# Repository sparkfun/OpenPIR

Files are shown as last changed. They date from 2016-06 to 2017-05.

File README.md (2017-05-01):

OpenPIR
==========

[OpenPIR Image*OpenPIR
(SEN-13968)*](https://www.sparkfun.com/products/13968)

OpenPIR is an open source general purpose passive long-wave infrared motion 
detection sensor.

Repository Contents
-------------------
* **/Documentation** - Datasheets for parts used in this design
* **/Hardware** - All Eagle design files
* **/Production** - Panel files used by SFE production for ordering

License Information
-------------------
The hardware is released under [Creative Commons Share-alike
4.0](http://creativecommons.org/licenses/by-sa/4.0/).  
All other code is open source so please feel free to do anything you want with
it; you buy me a beer if you use this and we meet someday ([Beerware
license](http://en.wikipedia.org/wiki/Beerware)).

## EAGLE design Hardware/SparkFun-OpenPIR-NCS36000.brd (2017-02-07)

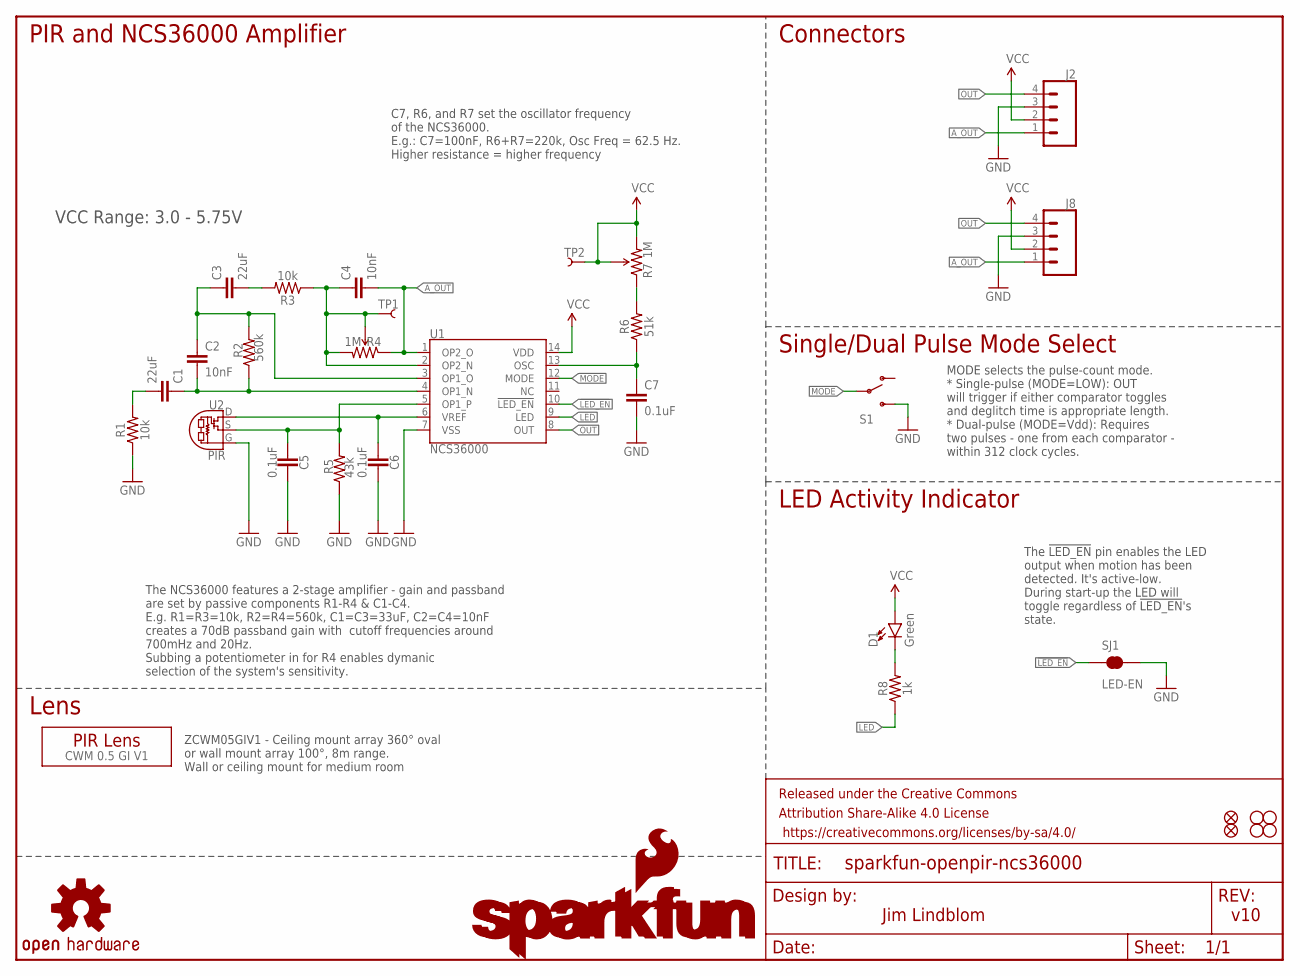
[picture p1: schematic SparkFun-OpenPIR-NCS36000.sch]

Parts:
C1, C3: 22uF; 0805
C2, C4: 10nF; 0603
C5, C6, C7: 0.1uF; 0603
D1: Green; LED-1206-BOTTOM
FD1, FD2: FIDUCIALUFIDUCIAL; MICRO-FIDUCIAL
FRAME1: FRAME-LETTER; CREATIVE_COMMONS
H1, H2, H3, H4: STAND-OFF
J2: CONN_04JST-PTH-VERT-NS; JST-4-PTH-VERT-NS
J8: CONN_04NO_SILK_ALL_ROUND; 1X04_NO_SILK_ALL_ROUND
LOGO1: SFE_LOGO_NAME_FLAME.1_INCH; SFE_LOGO_NAME_FLAME_.1
LOGO3: SFE_LOGO_NAME.1_INCH; SFE_LOGO_NAME_.1
LOGO4: OSHW-LOGOS; OSHW-LOGO-S
R1, R3: 10k; 0603
R2: 560k; 0603
R4, R7: 1M; TRIMPOT-TC33X
R5: 43k; 0603
R6: 51k; 0603
R8: 1k; 0603
S1: SWITCH-SPDT-SMD-A; SWITCH-SPST-SMD-A
SJ1: LED-EN; SJ_2S
TP1, TP2: TEST-POINT3X5; PAD.03X.05
U1: NCS36000; SO14
U2: PIR
U$1: CWM 0.5 GI V1; LENS-CWM-0.5-GI-V1

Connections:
!LED_EN!: SJ1.1, U1.10 (!LED_EN!)
A_OUT: C4.2, J2.1, J8.1, R4.1 (CCW), U1.1 (OP2_O)
GND: C5.2, C6.2, C7.2, J2.3, J8.3, R1.1, R5.1, S1.3 (S), SJ1.2, U1.7 (VSS), U2.G
LED: R8.1, U1.9 (LED)
MODE: S1.2, U1.12 (MODE)
unnamed: C5.1, R5.2, U1.5 (OP1_P), U2.S
unnamed: C6.1, U1.6 (VREF), U2.D
unnamed: C1.2, R1.2
unnamed: C3.2, R3.2
unnamed: C1.1, C2.2, R2.1, U1.4 (OP1_N)
unnamed: C2.1, C3.1, R2.2, U1.3 (OP1_O)
unnamed: C4.1, R3.1, R4.2 (WIPER), R4.3 (CW), TP1.P$1, U1.2 (OP2_N)
unnamed: C7.1, R6.1, U1.13 (OSC)
unnamed: D1.C, R8.2
unnamed: R6.2, R7.1 (CCW)
OUT: J2.4, J8.4, U1.8 (OUT)
VCC: D1.A, J2.2, J8.2, R7.2 (WIPER), R7.3 (CW), TP2.P$1, U1.14 (VDD)

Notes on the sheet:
The !LED_EN! pin enables the LED output when motion has been detected. It's active-low. During start-up the LED will toggle regardless of !LED_EN!'s state.
MODE selects the pulse-count mode. * Single-pulse (MODE=LOW): OUT will trigger if either comparator toggles and deglitch time is appropriate length. * Dual-pulse (MODE=Vdd): Requires two pulses - one from each comparator - within 312 clock cycles.
Jim Lindblom
v10
VCC Range: 3.0 - 5.75V
The NCS36000 features a 2-stage amplifier - gain and passband are set by passive components R1-R4 & C1-C4. E.g. R1=R3=10k, R2=R4=560k, C1=C3=33uF, C2=C4=10nF creates a 70dB passband gain with cutoff frequencies around 700mHz and 20Hz. Subbing a potentiometer in for R4 enables dymanic selection of t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
C7, R6, and R7 set the oscillator frequency of the NCS36000. E.g.: C7=100nF, R6+R7=220k, Osc Freq = 62.5 Hz. Higher resistance = higher frequency
ZCWM05GIV1 - Ceiling mount array 360° oval or wall mount array 100°, 8m range. Wall or ceiling mount for medium room
PIR and NCS36000 Amplifier
Connectors
Single/Dual Pulse Mode Select
LED Activity Indicator
Lens

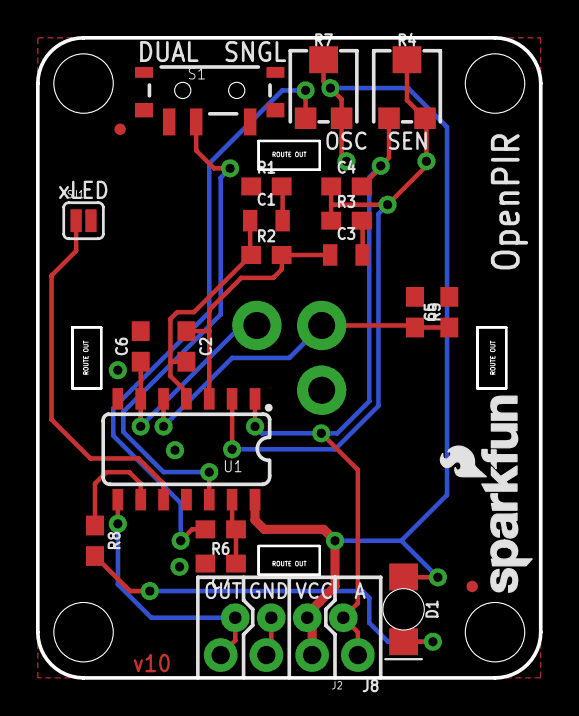
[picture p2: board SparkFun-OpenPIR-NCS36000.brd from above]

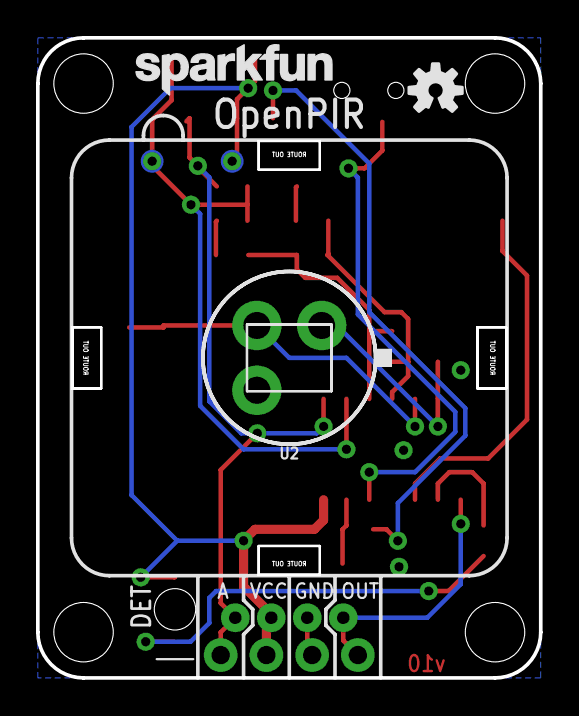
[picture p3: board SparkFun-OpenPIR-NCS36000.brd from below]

Board: 2 copper layers, 27.9 x 35.6 mm, 35 parts (6 on the bottom side), 17 nets.

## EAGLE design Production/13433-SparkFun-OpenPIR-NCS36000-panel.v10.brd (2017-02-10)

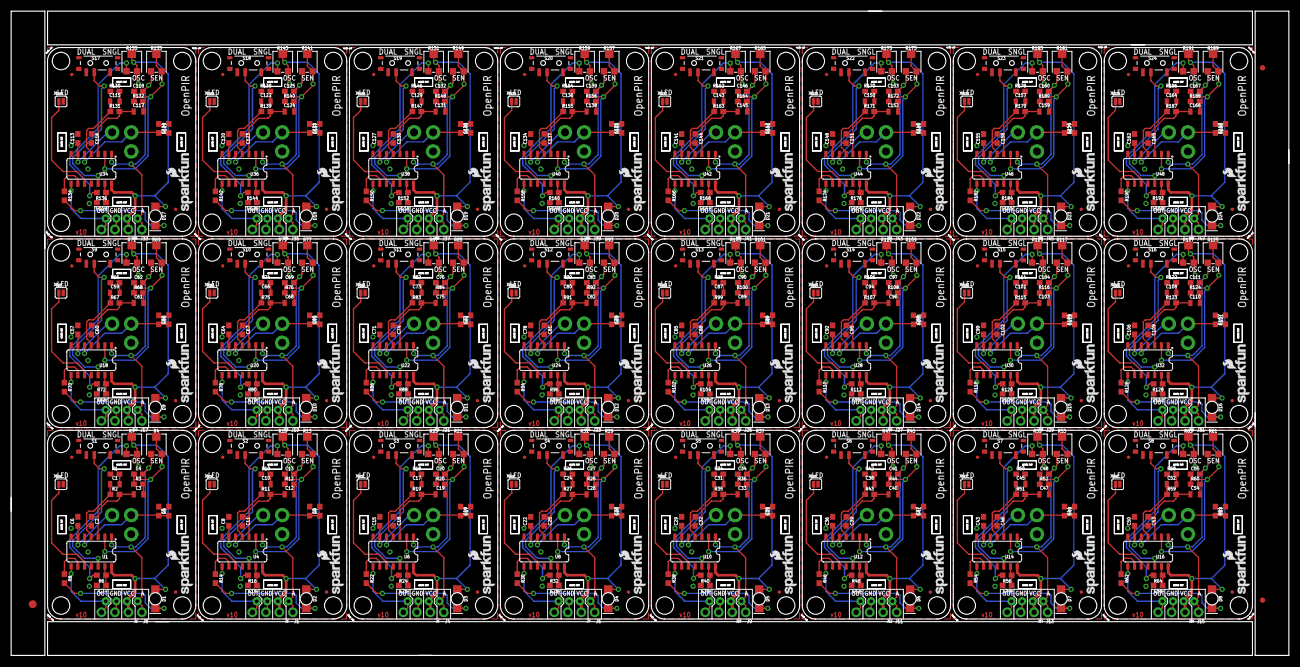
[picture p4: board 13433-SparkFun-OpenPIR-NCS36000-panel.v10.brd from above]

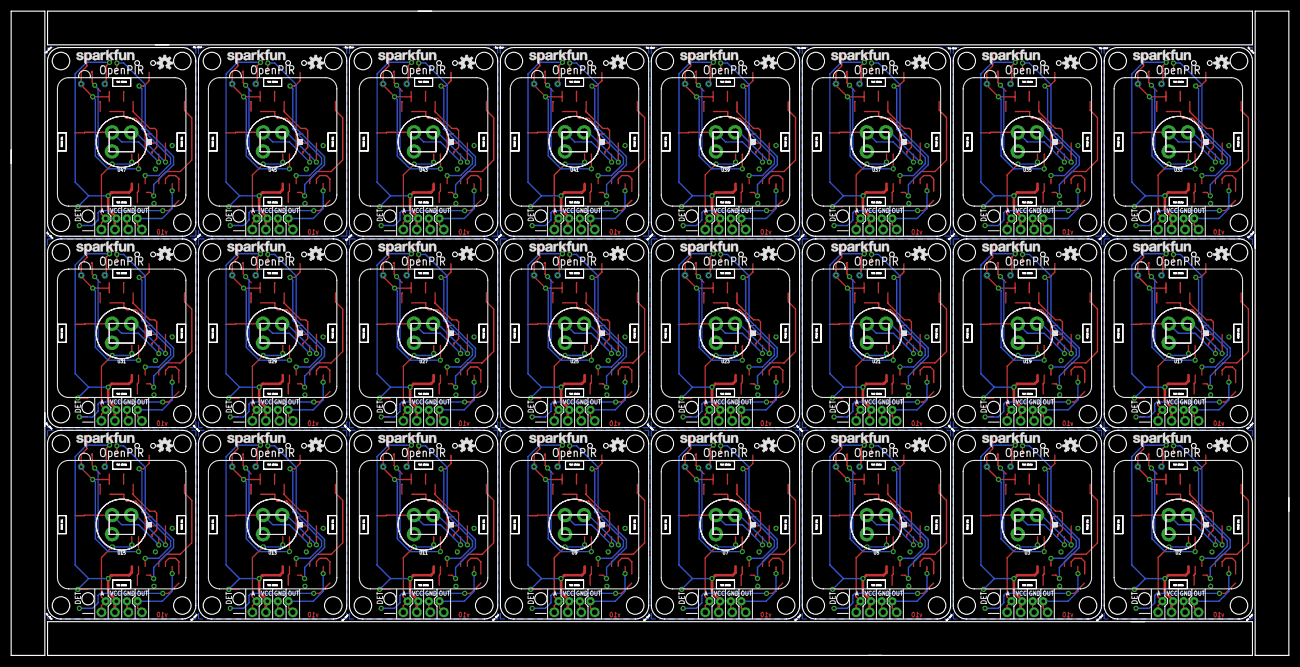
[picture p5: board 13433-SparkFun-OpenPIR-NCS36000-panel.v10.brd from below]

Board: 2 copper layers, 240.8 x 121.4 mm, 819 parts (144 on the bottom side), 408 nets.

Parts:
C1, C3, C10, C12, C17, C19, C24, C26, C31, C33, C38, C40, C45, C47, C52, C54, C59, C61, C66, C68, C73, C75, C80, C82, C87, C89, C94, C96, C101, C103, C108, C110, C115, C117, C122, C124, C129, C131, C136, C138, C143, C145, C150, C152, C157, C159, C164, C166: 22uF; 0805
C2, C4, C11, C13, C18, C20, C25, C27, C32, C34, C39, C41, C46, C48, C53, C55, C60, C62, C67, C69, C74, C76, C81, C83, C88, C90, C95, C97, C102, C104, C109, C111, C116, C118, C123, C125, C130, C132, C137, C139, C144, C146, C151, C153, C158, C160, C165, C167: 10nF; 0603
C5, C6, C7, C8, C9, C14, C15, C16, C21, C22, C23, C28, C29, C30, C35, C36, C37, C42, C43, C44, C49, C50, C51, C56, C57, C58, C63, C64, C65, C70, C71, C72, C77, C78, C79, C84, C85, C86, C91, C92, C93, C98, C99, C100, C105, C106, C107, C112, C113, C114, C119, C120, C121, C126, C127, C128, C133, C134, C135, C140, C141, C142, C147, C148, C149, C154, C155, C156, C161, C162, C163, C168: 0.1uF; 0603
D1, D2, D3, D4, D5, D6, D7, D8, D9, D10, D11, D12, D13, D14, D15, D16, D17, D18, D19, D20, D21, D22, D23, D24: Green; LED-1206-BOTTOM
E$1: FIDUCIAL-1.5X3
E$5, E$6: FIDUCIAL-1X2
FD1, FD2, FD3, FD4, FD5, FD6, FD7, FD8, FD9, FD10, FD11, FD12, FD13, FD14, FD15, FD16, FD17, FD18, FD19, FD20, FD21, FD22, FD23, FD24, FD25, FD26, FD27, FD28, FD29, FD30, FD31, FD32, FD33, FD34, FD35, FD36, FD37, FD38, FD39, FD40, FD41, FD42, FD43, FD44, FD45, FD46, FD47, FD48: FIDUCIALUFIDUCIAL; MICRO-FIDUCIAL
H1, H2, H3, H4, H5, H6, H7, H8, H9, H10, H11, H12, H13, H14, H15, H16, H17, H18, H19, H20, H21, H22, H23, H24, H25, H26, H27, H28, H29, H30, H31, H32, H33, H34, H35, H36, H37, H38, H39, H40, H41, H42, H43, H44, H45, H46, H47, H48, H49, H50, H51, H52, H53, H54, H55, H56, H57, H58, H59, H60, H61, H62, H63, H64, H65, H66, H67, H68, H69, H70, H71, H72, H73, H74, H75, H76, H77, H78, H79, H80, H81, H82, H83, H84, H85, H86, H87, H88, H89, H90, H91, H92, H93, H94, H95, H96: STAND-OFF
J1, J4, J6, J8, J9, J11, J13, J15, J17, J19, J21, J23, J25, J27, J29, J31, J33, J35, J37, J39, J41, J43, J45, J47: 1X04_NO_SILK_ALL_ROUND
J2, J3, J5, J7, J10, J12, J14, J16, J18, J20, J22, J24, J26, J28, J30, J32, J34, J36, J38, J40, J42, J44, J46, J48: JST-4-PTH-VERT-NS
LOGO1, LOGO2, LOGO7, LOGO10, LOGO13, LOGO16, LOGO19, LOGO22, LOGO25, LOGO28, LOGO31, LOGO34, LOGO37, LOGO40, LOGO43, LOGO46, LOGO49, LOGO52, LOGO55, LOGO58, LOGO61, LOGO64, LOGO67, LOGO70: SFE_LOGO_NAME_FLAME.1_INCH; SFE_LOGO_NAME_FLAME_.1
LOGO3, LOGO5, LOGO8, LOGO11, LOGO14, LOGO17, LOGO20, LOGO23, LOGO26, LOGO29, LOGO32, LOGO35, LOGO38, LOGO41, LOGO44, LOGO47, LOGO50, LOGO53, LOGO56, LOGO59, LOGO62, LOGO65, LOGO68, LOGO71: SFE_LOGO_NAME.1_INCH; SFE_LOGO_NAME_.1
LOGO4, LOGO6, LOGO9, LOGO12, LOGO15, LOGO18, LOGO21, LOGO24, LOGO27, LOGO30, LOGO33, LOGO36, LOGO39, LOGO42, LOGO45, LOGO48, LOGO51, LOGO54, LOGO57, LOGO60, LOGO63, LOGO66, LOGO69, LOGO72: OSHW-LOGOS; OSHW-LOGO-S
R1, R3, R10, R12, R18, R20, R26, R28, R34, R36, R42, R44, R50, R52, R58, R60, R66, R68, R74, R76, R82, R84, R90, R92, R98, R100, R106, R108, R114, R116, R122, R124, R130, R132, R138, R140, R146, R148, R154, R156, R162, R164, R170, R172, R178, R180, R186, R188: 10k; 0603
R2, R11, R19, R27, R35, R43, R51, R59, R67, R75, R83, R91, R99, R107, R115, R123, R131, R139, R147, R155, R163, R171, R179, R187: 560k; 0603
R4, R7, R13, R15, R21, R23, R29, R31, R37, R39, R45, R47, R53, R55, R61, R63, R69, R71, R77, R79, R85, R87, R93, R95, R101, R103, R109, R111, R117, R119, R125, R127, R133, R135, R141, R143, R149, R151, R157, R159, R165, R167, R173, R175, R181, R183, R189, R191: 1M; TRIMPOT-TC33X
R5, R9, R17, R25, R33, R41, R49, R57, R65, R73, R81, R89, R97, R105, R113, R121, R129, R137, R145, R153, R161, R169, R177, R185: 43k; 0603
R6, R16, R24, R32, R40, R48, R56, R64, R72, R80, R88, R96, R104, R112, R120, R128, R136, R144, R152, R160, R168, R176, R184, R192: 51k; 0603
R8, R14, R22, R30, R38, R46, R54, R62, R70, R78, R86, R94, R102, R110, R118, R126, R134, R142, R150, R158, R166, R174, R182, R190: 1k; 0603
S1, S2, S3, S4, S5, S6, S7, S8, S9, S10, S11, S12, S13, S14, S15, S16, S17, S18, S19, S20, S21, S22, S23, S24: SWITCH-SPST-SMD-A
SJ1, SJ2, SJ3, SJ4, SJ5, SJ6, SJ7, SJ8, SJ9, SJ10, SJ11, SJ12, SJ13, SJ14, SJ15, SJ16, SJ17, SJ18, SJ19, SJ20, SJ21, SJ22, SJ23, SJ24: LED-EN; SJ_2S
TP1, TP2, TP3, TP4, TP5, TP6, TP7, TP8, TP9, TP10, TP11, TP12, TP13, TP14, TP15, TP16, TP17, TP18, TP19, TP20, TP21, TP22, TP23, TP24, TP25, TP26, TP27, TP28, TP29, TP30, TP31, TP32, TP33, TP34, TP35, TP36, TP37, TP38, TP39, TP40, TP41, TP42, TP43, TP44, TP45, TP46, TP47, TP48: PAD.03X.05
U1, U4, U6, U8, U10, U12, U14, U16, U18, U20, U22, U24, U26, U28, U30, U32, U34, U36, U38, U40, U42, U44, U46, U48: NCS36000; SO14
U2, U3, U5, U7, U9, U11, U13, U15, U17, U19, U21, U23, U25, U27, U29, U31, U33, U35, U37, U39, U41, U43, U45, U47: PIR
U$1, U$2, U$3, U$4, U$5, U$6, U$7, U$8, U$9, U$10, U$11, U$12, U$13, U$14, U$15, U$16, U$17, U$18, U$19, U$20, U$21, U$22, U$23, U$24: CWM 0.5 GI V1; LENS-CWM-0.5-GI-V1

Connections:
!LED_EN!: SJ1.1, U1.10
!LED_EN!1: SJ2.1, U4.10
!LED_EN!2: SJ3.1, U6.10
!LED_EN!3: SJ4.1, U8.10
!LED_EN!4: SJ5.1, U10.10
!LED_EN!5: SJ6.1, U12.10
!LED_EN!6: SJ7.1, U14.10
!LED_EN!7: SJ8.1, U16.10
!LED_EN!8: SJ9.1, U18.10
!LED_EN!9: SJ10.1, U20.10
!LED_EN!10: SJ11.1, U22.10
!LED_EN!11: SJ12.1, U24.10
!LED_EN!12: SJ13.1, U26.10
!LED_EN!13: SJ14.1, U28.10
!LED_EN!14: SJ15.1, U30.10
!LED_EN!15: SJ16.1, U32.10
!LED_EN!16: SJ17.1, U34.10
!LED_EN!17: SJ18.1, U36.10
!LED_EN!18: SJ19.1, U38.10
!LED_EN!19: SJ20.1, U40.10
!LED_EN!20: SJ21.1, U42.10
!LED_EN!21: SJ22.1, U44.10
!LED_EN!22: SJ23.1, U46.10
!LED_EN!23: SJ24.1, U48.10
A_OUT: C4.2, J2.1, J8.1, R4.1, U1.1
A_OUT1: C13.2, J1.1, J3.1, R13.1, U4.1
A_OUT2: C20.2, J4.1, J5.1, R21.1, U6.1
A_OUT3: C27.2, J6.1, J7.1, R29.1, U8.1
A_OUT4: C34.2, J9.1, J10.1, R37.1, U10.1
A_OUT5: C41.2, J11.1, J12.1, R45.1, U12.1
A_OUT6: C48.2, J13.1, J14.1, R53.1, U14.1
A_OUT7: C55.2, J15.1, J16.1, R61.1, U16.1
A_OUT8: C62.2, J17.1, J18.1, R69.1, U18.1
A_OUT9: C69.2, J19.1, J20.1, R77.1, U20.1
A_OUT10: C76.2, J21.1, J22.1, R85.1, U22.1
A_OUT11: C83.2, J23.1, J24.1, R93.1, U24.1
A_OUT12: C90.2, J25.1, J26.1, R101.1, U26.1
A_OUT13: C97.2, J27.1, J28.1, R109.1, U28.1
A_OUT14: C104.2, J29.1, J30.1, R117.1, U30.1
A_OUT15: C111.2, J31.1, J32.1, R125.1, U32.1
A_OUT16: C118.2, J33.1, J34.1, R133.1, U34.1
A_OUT17: C125.2, J35.1, J36.1, R141.1, U36.1
A_OUT18: C132.2, J37.1, J38.1, R149.1, U38.1
A_OUT19: C139.2, J39.1, J40.1, R157.1, U40.1
A_OUT20: C146.2, J41.1, J42.1, R165.1, U42.1
A_OUT21: C153.2, J43.1, J44.1, R173.1, U44.1
A_OUT22: C160.2, J45.1, J46.1, R181.1, U46.1
A_OUT23: C167.2, J47.1, J48.1, R189.1, U48.1
GND: C5.2, C6.2, C7.2, J2.3, J8.3, R1.1, R5.1, S1.3, SJ1.2, U1.7, U2.G
GND1: C8.2, C9.2, C14.2, J1.3, J3.3, R9.1, R10.1, S2.3, SJ2.2, U3.G, U4.7
GND2: C15.2, C16.2, C21.2, J4.3, J5.3, R17.1, R18.1, S3.3, SJ3.2, U5.G, U6.7
GND3: C22.2, C23.2, C28.2, J6.3, J7.3, R25.1, R26.1, S4.3, SJ4.2, U7.G, U8.7
GND4: C29.2, C30.2, C35.2, J9.3, J10.3, R33.1, R34.1, S5.3, SJ5.2, U9.G, U10.7
GND5: C36.2, C37.2, C42.2, J11.3, J12.3, R41.1, R42.1, S6.3, SJ6.2, U11.G, U12.7
GND6: C43.2, C44.2, C49.2, J13.3, J14.3, R49.1, R50.1, S7.3, SJ7.2, U13.G, U14.7
GND7: C50.2, C51.2, C56.2, J15.3, J16.3, R57.1, R58.1, S8.3, SJ8.2, U15.G, U16.7
GND8: C57.2, C58.2, C63.2, J17.3, J18.3, R65.1, R66.1, S9.3, SJ9.2, U17.G, U18.7
GND9: C64.2, C65.2, C70.2, J19.3, J20.3, R73.1, R74.1, S10.3, SJ10.2, U19.G, U20.7
GND10: C71.2, C72.2, C77.2, J21.3, J22.3, R81.1, R82.1, S11.3, SJ11.2, U21.G, U22.7
GND11: C78.2, C79.2, C84.2, J23.3, J24.3, R89.1, R90.1, S12.3, SJ12.2, U23.G, U24.7
GND12: C85.2, C86.2, C91.2, J25.3, J26.3, R97.1, R98.1, S13.3, SJ13.2, U25.G, U26.7
GND13: C92.2, C93.2, C98.2, J27.3, J28.3, R105.1, R106.1, S14.3, SJ14.2, U27.G, U28.7
GND14: C99.2, C100.2, C105.2, J29.3, J30.3, R113.1, R114.1, S15.3, SJ15.2, U29.G, U30.7
GND15: C106.2, C107.2, C112.2, J31.3, J32.3, R121.1, R122.1, S16.3, SJ16.2, U31.G, U32.7
GND16: C113.2, C114.2, C119.2, J33.3, J34.3, R129.1, R130.1, S17.3, SJ17.2, U33.G, U34.7
GND17: C120.2, C121.2, C126.2, J35.3, J36.3, R137.1, R138.1, S18.3, SJ18.2, U35.G, U36.7
GND18: C127.2, C128.2, C133.2, J37.3, J38.3, R145.1, R146.1, S19.3, SJ19.2, U37.G, U38.7
GND19: C134.2, C135.2, C140.2, J39.3, J40.3, R153.1, R154.1, S20.3, SJ20.2, U39.G, U40.7
GND20: C141.2, C142.2, C147.2, J41.3, J42.3, R161.1, R162.1, S21.3, SJ21.2, U41.G, U42.7
GND21: C148.2, C149.2, C154.2, J43.3, J44.3, R169.1, R170.1, S22.3, SJ22.2, U43.G, U44.7
GND22: C155.2, C156.2, C161.2, J45.3, J46.3, R177.1, R178.1, S23.3, SJ23.2, U45.G, U46.7
GND23: C162.2, C163.2, C168.2, J47.3, J48.3, R185.1, R186.1, S24.3, SJ24.2, U47.G, U48.7
LED: R8.1, U1.9
LED1: R14.1, U4.9
LED2: R22.1, U6.9
LED3: R30.1, U8.9
LED4: R38.1, U10.9
LED5: R46.1, U12.9
LED6: R54.1, U14.9
LED7: R62.1, U16.9
LED8: R70.1, U18.9
LED9: R78.1, U20.9
LED10: R86.1, U22.9
LED11: R94.1, U24.9
LED12: R102.1, U26.9
LED13: R110.1, U28.9
LED14: R118.1, U30.9
LED15: R126.1, U32.9
LED16: R134.1, U34.9
LED17: R142.1, U36.9
LED18: R150.1, U38.9
LED19: R158.1, U40.9
LED20: R166.1, U42.9
LED21: R174.1, U44.9
LED22: R182.1, U46.9
LED23: R190.1, U48.9
MODE: S1.2, U1.12
MODE1: S2.2, U4.12
MODE2: S3.2, U6.12
MODE3: S4.2, U8.12
MODE4: S5.2, U10.12
MODE5: S6.2, U12.12
MODE6: S7.2, U14.12
MODE7: S8.2, U16.12
MODE8: S9.2, U18.12
MODE9: S10.2, U20.12
MODE10: S11.2, U22.12
MODE11: S12.2, U24.12
MODE12: S13.2, U26.12
MODE13: S14.2, U28.12
MODE14: S15.2, U30.12
MODE15: S16.2, U32.12
MODE16: S17.2, U34.12
MODE17: S18.2, U36.12
MODE18: S19.2, U38.12
MODE19: S20.2, U40.12
MODE20: S21.2, U42.12
MODE21: S22.2, U44.12
MODE22: S23.2, U46.12
MODE23: S24.2, U48.12
unnamed: C5.1, R5.2, U1.5, U2.S
unnamed: C6.1, U1.6, U2.D
unnamed: C1.2, R1.2
unnamed: C3.2, R3.2
unnamed: C1.1, C2.2, R2.1, U1.4
unnamed: C2.1, C3.1, R2.2, U1.3
unnamed: C4.1, R3.1, R4.2, R4.3, TP1.P$1, U1.2
unnamed: C7.1, R6.1, U1.13
unnamed: D1.C, R8.2
unnamed: C8.1, U3.D, U4.6
unnamed: R6.2, R7.1
unnamed: C9.1, R9.2, U3.S, U4.5
unnamed: C10.2, R10.2
unnamed: C12.2, R12.2
unnamed: C10.1, C11.2, R11.1, U4.4
unnamed: C11.1, C12.1, R11.2, U4.3
unnamed: C13.1, R12.1, R13.2, R13.3, TP3.P$1, U4.2
unnamed: C14.1, R16.1, U4.13
unnamed: D2.C, R14.2
unnamed: R15.1, R16.2
unnamed: C15.1, U5.D, U6.6
unnamed: C16.1, R17.2, U5.S, U6.5
unnamed: C17.2, R18.2
unnamed: C19.2, R20.2
unnamed: C17.1, C18.2, R19.1, U6.4
unnamed: C18.1, C19.1, R19.2, U6.3
unnamed: C20.1, R20.1, R21.2, R21.3, TP5.P$1, U6.2
unnamed: C21.1, R24.1, U6.13
unnamed: D3.C, R22.2
unnamed: R23.1, R24.2
unnamed: C22.1, U7.D, U8.6
unnamed: C23.1, R25.2, U7.S, U8.5
unnamed: C24.2, R26.2
unnamed: C26.2, R28.2
unnamed: C24.1, C25.2, R27.1, U8.4
unnamed: C25.1, C26.1, R27.2, U8.3
unnamed: C27.1, R28.1, R29.2, R29.3, TP7.P$1, U8.2
unnamed: C28.1, R32.1, U8.13
unnamed: D4.C, R30.2
unnamed: R31.1, R32.2
unnamed: C29.1, U9.D, U10.6
unnamed: C30.1, R33.2, U9.S, U10.5
unnamed: C31.2, R34.2
unnamed: C33.2, R36.2
unnamed: C31.1, C32.2, R35.1, U10.4
unnamed: C32.1, C33.1, R35.2, U10.3
unnamed: C34.1, R36.1, R37.2, R37.3, TP9.P$1, U10.2
unnamed: C35.1, R40.1, U10.13
unnamed: D5.C, R38.2
unnamed: R39.1, R40.2
unnamed: C36.1, U11.D, U12.6
unnamed: C37.1, R41.2, U11.S, U12.5
unnamed: C38.2, R42.2
unnamed: C40.2, R44.2
unnamed: C38.1, C39.2, R43.1, U12.4
unnamed: C39.1, C40.1, R43.2, U12.3
unnamed: C41.1, R44.1, R45.2, R45.3, TP11.P$1, U12.2
unnamed: C42.1, R48.1, U12.13
unnamed: D6.C, R46.2
unnamed: R47.1, R48.2
unnamed: C43.1, U13.D, U14.6
unnamed: C44.1, R49.2, U13.S, U14.5
unnamed: C45.2, R50.2
unnamed: C47.2, R52.2
unnamed: C45.1, C46.2, R51.1, U14.4
unnamed: C46.1, C47.1, R51.2, U14.3
unnamed: C48.1, R52.1, R53.2, R53.3, TP13.P$1, U14.2
unnamed: C49.1, R56.1, U14.13
unnamed: D7.C, R54.2
unnamed: R55.1, R56.2
unnamed: C50.1, U15.D, U16.6
unnamed: C51.1, R57.2, U15.S, U16.5
unnamed: C52.2, R58.2
unnamed: C54.2, R60.2
unnamed: C52.1, C53.2, R59.1, U16.4
unnamed: C53.1, C54.1, R59.2, U16.3
unnamed: C55.1, R60.1, R61.2, R61.3, TP15.P$1, U16.2
unnamed: C56.1, R64.1, U16.13
unnamed: D8.C, R62.2
unnamed: R63.1, R64.2
unnamed: C57.1, U17.D, U18.6
unnamed: C58.1, R65.2, U17.S, U18.5
unnamed: C59.2, R66.2
unnamed: C61.2, R68.2
unnamed: C59.1, C60.2, R67.1, U18.4
unnamed: C60.1, C61.1, R67.2, U18.3
unnamed: C62.1, R68.1, R69.2, R69.3, TP17.P$1, U18.2
unnamed: C63.1, R72.1, U18.13
unnamed: D9.C, R70.2
unnamed: R71.1, R72.2
unnamed: C64.1, U19.D, U20.6
unnamed: C65.1, R73.2, U19.S, U20.5
unnamed: C66.2, R74.2
unnamed: C68.2, R76.2
unnamed: C66.1, C67.2, R75.1, U20.4
unnamed: C67.1, C68.1, R75.2, U20.3
unnamed: C69.1, R76.1, R77.2, R77.3, TP19.P$1, U20.2
unnamed: C70.1, R80.1, U20.13
unnamed: D10.C, R78.2
unnamed: R79.1, R80.2
unnamed: C71.1, U21.D, U22.6
unnamed: C72.1, R81.2, U21.S, U22.5
unnamed: C73.2, R82.2
unnamed: C75.2, R84.2
unnamed: C73.1, C74.2, R83.1, U22.4
unnamed: C74.1, C75.1, R83.2, U22.3
unnamed: C76.1, R84.1, R85.2, R85.3, TP21.P$1, U22.2
unnamed: C77.1, R88.1, U22.13
unnamed: D11.C, R86.2
unnamed: R87.1, R88.2
unnamed: C78.1, U23.D, U24.6
unnamed: C79.1, R89.2, U23.S, U24.5
unnamed: C80.2, R90.2
unnamed: C82.2, R92.2
unnamed: C80.1, C81.2, R91.1, U24.4
unnamed: C81.1, C82.1, R91.2, U24.3
unnamed: C83.1, R92.1, R93.2, R93.3, TP23.P$1, U24.2
unnamed: C84.1, R96.1, U24.13
unnamed: D12.C, R94.2
unnamed: R95.1, R96.2
unnamed: C85.1, U25.D, U26.6
unnamed: C86.1, R97.2, U25.S, U26.5
unnamed: C87.2, R98.2
unnamed: C89.2, R100.2
unnamed: C87.1, C88.2, R99.1, U26.4
unnamed: C88.1, C89.1, R99.2, U26.3
unnamed: C90.1, R100.1, R101.2, R101.3, TP25.P$1, U26.2
unnamed: C91.1, R104.1, U26.13
unnamed: D13.C, R102.2
unnamed: R103.1, R104.2
unnamed: C92.1, U27.D, U28.6
unnamed: C93.1, R105.2, U27.S, U28.5
unnamed: C94.2, R106.2
unnamed: C96.2, R108.2
unnamed: C94.1, C95.2, R107.1, U28.4
unnamed: C95.1, C96.1, R107.2, U28.3
unnamed: C97.1, R108.1, R109.2, R109.3, TP27.P$1, U28.2
unnamed: C98.1, R112.1, U28.13
unnamed: D14.C, R110.2
unnamed: R111.1, R112.2
unnamed: C99.1, U29.D, U30.6
unnamed: C100.1, R113.2, U29.S, U30.5
unnamed: C101.2, R114.2
unnamed: C103.2, R116.2
unnamed: C101.1, C102.2, R115.1, U30.4
unnamed: C102.1, C103.1, R115.2, U30.3
unnamed: C104.1, R116.1, R117.2, R117.3, TP29.P$1, U30.2
unnamed: C105.1, R120.1, U30.13
unnamed: D15.C, R118.2
unnamed: R119.1, R120.2
unnamed: C106.1, U31.D, U32.6
unnamed: C107.1, R121.2, U31.S, U32.5
unnamed: C108.2, R122.2
unnamed: C110.2, R124.2
unnamed: C108.1, C109.2, R123.1, U32.4
unnamed: C109.1, C110.1, R123.2, U32.3
unnamed: C111.1, R124.1, R125.2, R125.3, TP31.P$1, U32.2
unnamed: C112.1, R128.1, U32.13
unnamed: D16.C, R126.2
unnamed: R127.1, R128.2
unnamed: C113.1, U33.D, U34.6
unnamed: C114.1, R129.2, U33.S, U34.5
unnamed: C115.2, R130.2
unnamed: C117.2, R132.2
unnamed: C115.1, C116.2, R131.1, U34.4
unnamed: C116.1, C117.1, R131.2, U34.3
unnamed: C118.1, R132.1, R133.2, R133.3, TP33.P$1, U34.2
unnamed: C119.1, R136.1, U34.13
unnamed: D17.C, R134.2
unnamed: R135.1, R136.2
unnamed: C120.1, U35.D, U36.6
unnamed: C121.1, R137.2, U35.S, U36.5
unnamed: C122.2, R138.2
unnamed: C124.2, R140.2
unnamed: C122.1, C123.2, R139.1, U36.4
unnamed: C123.1, C124.1, R139.2, U36.3
unnamed: C125.1, R140.1, R141.2, R141.3, TP35.P$1, U36.2
unnamed: C126.1, R144.1, U36.13
unnamed: D18.C, R142.2
unnamed: R143.1, R144.2
unnamed: C127.1, U37.D, U38.6
unnamed: C128.1, R145.2, U37.S, U38.5
unnamed: C129.2, R146.2
unnamed: C131.2, R148.2
unnamed: C129.1, C130.2, R147.1, U38.4
unnamed: C130.1, C131.1, R147.2, U38.3
unnamed: C132.1, R148.1, R149.2, R149.3, TP37.P$1, U38.2
unnamed: C133.1, R152.1, U38.13
unnamed: D19.C, R150.2
unnamed: R151.1, R152.2
unnamed: C134.1, U39.D, U40.6
unnamed: C135.1, R153.2, U39.S, U40.5
unnamed: C136.2, R154.2
unnamed: C138.2, R156.2
unnamed: C136.1, C137.2, R155.1, U40.4
unnamed: C137.1, C138.1, R155.2, U40.3
unnamed: C139.1, R156.1, R157.2, R157.3, TP39.P$1, U40.2
unnamed: C140.1, R160.1, U40.13
unnamed: D20.C, R158.2
unnamed: R159.1, R160.2
unnamed: C141.1, U41.D, U42.6
unnamed: C142.1, R161.2, U41.S, U42.5
unnamed: C143.2, R162.2
unnamed: C145.2, R164.2
unnamed: C143.1, C144.2, R163.1, U42.4
unnamed: C144.1, C145.1, R163.2, U42.3
unnamed: C146.1, R164.1, R165.2, R165.3, TP41.P$1, U42.2
unnamed: C147.1, R168.1, U42.13
unnamed: D21.C, R166.2
unnamed: R167.1, R168.2
unnamed: C148.1, U43.D, U44.6
unnamed: C149.1, R169.2, U43.S, U44.5
unnamed: C150.2, R170.2
unnamed: C152.2, R172.2
unnamed: C150.1, C151.2, R171.1, U44.4
unnamed: C151.1, C152.1, R171.2, U44.3
unnamed: C153.1, R172.1, R173.2, R173.3, TP43.P$1, U44.2
unnamed: C154.1, R176.1, U44.13
unnamed: D22.C, R174.2
unnamed: R175.1, R176.2
unnamed: C155.1, U45.D, U46.6
unnamed: C156.1, R177.2, U45.S, U46.5
unnamed: C157.2, R178.2
unnamed: C159.2, R180.2
unnamed: C157.1, C158.2, R179.1, U46.4
unnamed: C158.1, C159.1, R179.2, U46.3
unnamed: C160.1, R180.1, R181.2, R181.3, TP45.P$1, U46.2
unnamed: C161.1, R184.1, U46.13
unnamed: D23.C, R182.2
unnamed: R183.1, R184.2
unnamed: C162.1, U47.D, U48.6
unnamed: C163.1, R185.2, U47.S, U48.5
unnamed: C164.2, R186.2
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

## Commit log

2016-06-20 Initial commit of hardware.
    [SparkFun-OpenPIR-NCS36000.brd, SparkFun-OpenPIR-NCS36000.sch]
2016-06-21 Swapping 33uF cap packages to 1206.
    [SparkFun-OpenPIR-NCS36000.brd, SparkFun-OpenPIR-NCS36000.sch]
2016-06-21 Updating sch and brd after running checklist.
    [SparkFun-OpenPIR-NCS36000.brd, SparkFun-OpenPIR-NCS36000.sch]
2016-06-24 Moving route out text to design.
    [SparkFun-OpenPIR-NCS36000.brd, SparkFun-OpenPIR-NCS36000.sch]
2016-06-24 created PROTO panel v01
    [SparkFun-OpenPIR-NCS36000_PROTO_Panel_v01.brd]
2017-01-04 Remove a few lenses, re-wire pot, re-routing
    - Removed ZAA09GIT1 lens & PTH holes that would hold it in. (Would be mounted at incorrect curve/distance.)
    - Removed ZNCL11 lens. Low stock, uncommon footprint.
    - Re-wired sensitivity pot so "turning it up" increases sensitivity.
    - Re-routing now that there are fewer mill-outs and holes.
    [SparkFun-OpenPIR-NCS36000.brd, SparkFun-OpenPIR-NCS36000.sch]
2017-01-04 Moving xLED jumper to more accessible location
    [SparkFun-OpenPIR-NCS36000.brd]
2017-01-09 Removing tStop from PIR sensor - expose copper on solder-side only.
    [SparkFun-OpenPIR-NCS36000.brd, SparkFun-OpenPIR-NCS36000.sch]
2017-01-09 Revising pin labels
    [SparkFun-OpenPIR-NCS36000.brd]
2017-01-10 Adding test points to trimpot wipers
    [SparkFun-OpenPIR-NCS36000.brd, SparkFun-OpenPIR-NCS36000.sch]
2017-01-10 Replacing text logo with text+flame, moving schematic fids.
    [SparkFun-OpenPIR-NCS36000.brd, SparkFun-OpenPIR-NCS36000.sch]
2017-01-11 Adding dimension layer outline to lens notch cutouts.
    [SparkFun-OpenPIR-NCS36000.brd, SparkFun-OpenPIR-NCS36000.sch]
2017-01-31 Minor silkscreen adjustments. Incrementing to v10.
    [SparkFun-OpenPIR-NCS36000.brd, SparkFun-OpenPIR-NCS36000.sch]
2017-02-02 Fixing lens silkscreen, and moving r's, c's away from PIR sensor.
    [SparkFun-OpenPIR-NCS36000.brd, SparkFun-OpenPIR-NCS36000.sch]
2017-02-07 Adding description to PIR lens.
2017-02-07 Moving C6 a bit, minor re-routing.
    [SparkFun-OpenPIR-NCS36000.brd]

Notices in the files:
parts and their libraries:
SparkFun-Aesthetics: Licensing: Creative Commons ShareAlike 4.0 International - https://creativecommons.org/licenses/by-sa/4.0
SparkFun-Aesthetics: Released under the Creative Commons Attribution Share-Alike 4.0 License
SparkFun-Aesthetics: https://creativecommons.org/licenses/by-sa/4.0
